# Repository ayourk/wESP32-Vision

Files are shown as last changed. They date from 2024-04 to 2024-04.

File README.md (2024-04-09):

# wESP32-Vision
OV2640 Camera module AddOn board for wESP32

## Description
This is my reinterpretation of [@xorbit](https://github.com/xorbit)'s Camera module prototype.  Sample Arduino project included.

### PCB Layout
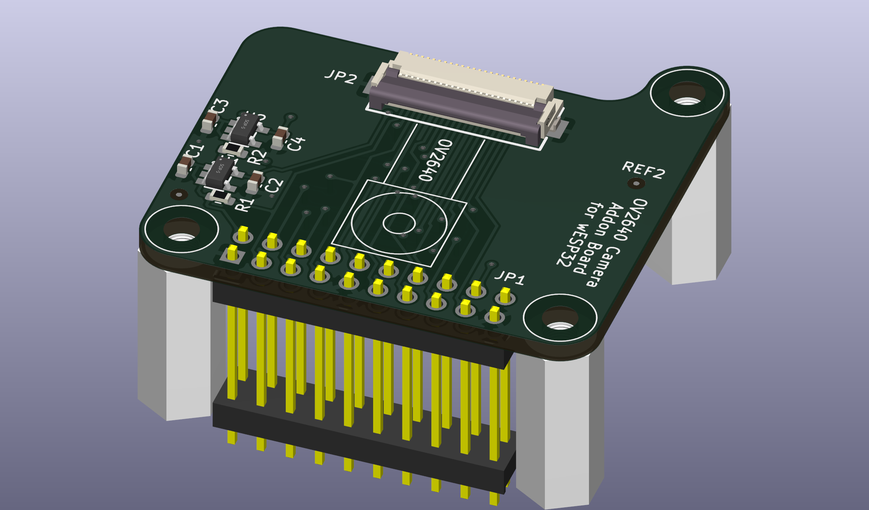
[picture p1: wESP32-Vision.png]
wESP32-Vision Board Image Apple II Prototyping Expansion Card (mini version)


### See Also
[xorbit's Projects](https://github.com/xorbit?tab=repositories)

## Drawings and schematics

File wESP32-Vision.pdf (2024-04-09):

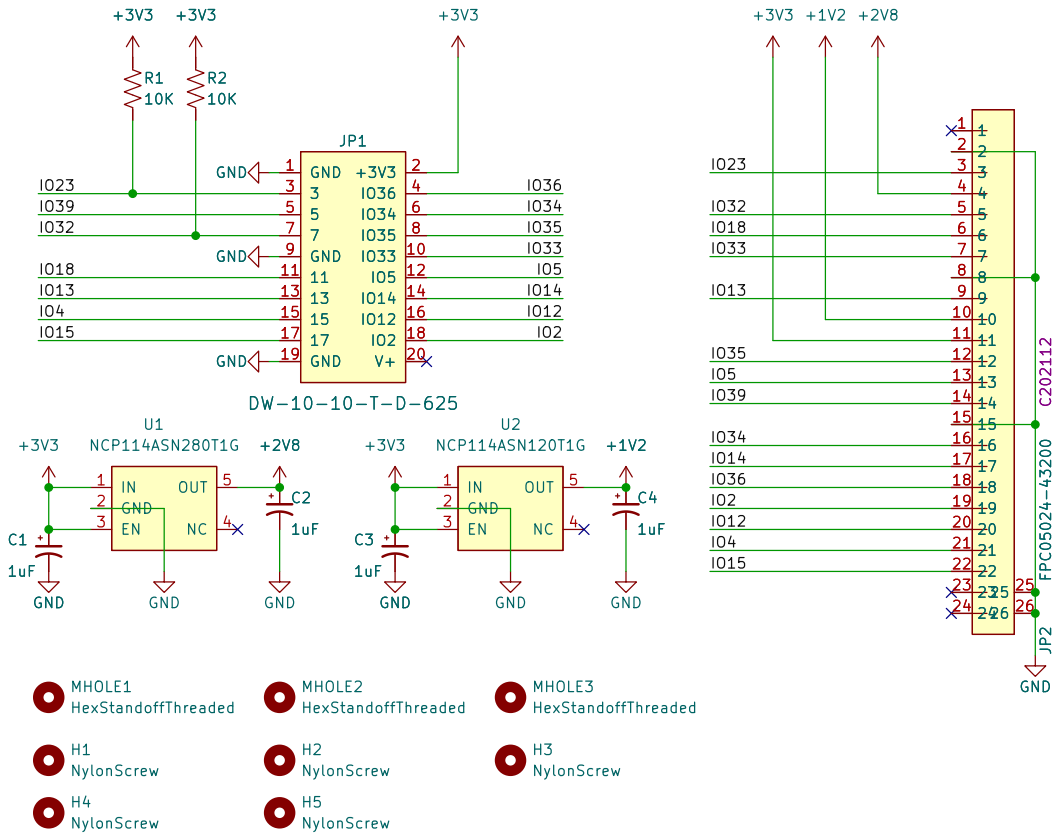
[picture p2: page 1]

Id: 1/1 Title: wESP32 Vision OV2640 Camera Addon Board

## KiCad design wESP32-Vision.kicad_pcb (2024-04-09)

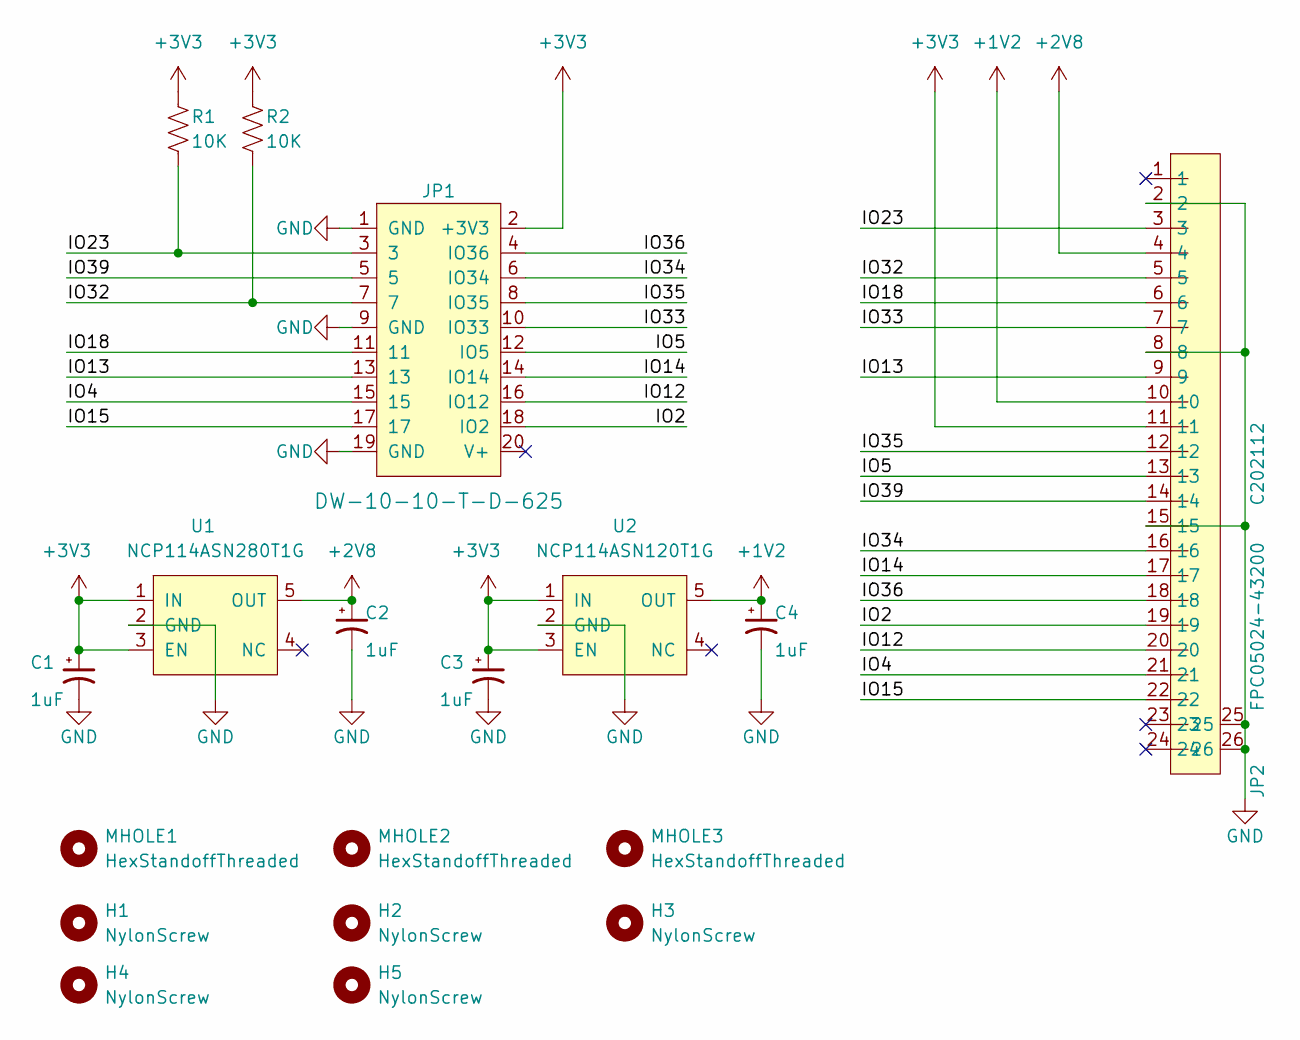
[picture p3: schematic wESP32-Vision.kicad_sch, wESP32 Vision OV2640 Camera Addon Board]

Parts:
C1, C2, C3, C4: 1uF; C_0603_1608Metric; MPN CL10A105KB8NNNC; Digi-Key_PN 1276-1860-1-ND
H1, H2, H3, H4, H5: NylonScrew; Screw; MPN 010440WF025; Digi-Key_PN RPC7726-ND
JP1: DW-10-10-T-D-625; SAMTEC_DW-10-XX-X-D-XXX; MPN DW-10-10-T-D-625; LCSC C62032
JP2: FPC05024-43200; FPC-SMD_FH12-24S-0.5SH-55; MPN FH12-24S-0.5SH(55); Digi-Key_PN HFJ124CT-ND
MHOLE1, MHOLE2, MHOLE3: HexStandoffThreaded; MountingHole_3mm; MPN 1902F; Digi-Key_PN 36-1902F-ND
R1, R2: 10K; R_0603_1608Metric; MPN ERJ-UP3F1002V; Digi-Key_PN 10-ERJ-UP3F1002VCT-ND
U1: NCP114ASN280T1G; TSOP-5_L3.0-W1.5-P0.95-LS2.8-BL; MPN NCP114ASN280T1G; LCSC C504890
U2: NCP114ASN120T1G; TSOP-5_L3.0-W1.5-P0.95-LS2.8-BL; MPN NCP114ASN120T1G; LCSC C512862

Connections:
+1V2: C4.1, JP2.10, U2.5 (OUT)
+2V8: C2.1, JP2.4, U1.5 (OUT)
+3V3: C1.1, C3.1, JP1.2 (+3V3), JP2.11, R1.1, R2.1, U1.1 (IN), U1.3 (EN), U2.1 (IN), U2.3 (EN)
/IO2: JP1.18 (IO2), JP2.19
/IO4: JP1.15, JP2.21
/IO5: JP1.12 (IO5), JP2.13
/IO12: JP1.16 (IO12), JP2.20
/IO13: JP1.13, JP2.9
/IO14: JP1.14 (IO14), JP2.17
/IO15: JP1.17, JP2.22
/IO18: JP1.11, JP2.6
/IO23: JP1.3, JP2.3, R1.2
/IO32: JP1.7, JP2.5, R2.2
/IO33: JP1.10 (IO33), JP2.7
/IO34: JP1.6 (IO34), JP2.16
/IO35: JP1.8 (IO35), JP2.12
/IO36: JP1.4 (IO36), JP2.18
/IO39: JP1.5, JP2.14
GND: C1.2, C2.2, C3.2, C4.2, JP1.1 (GND), JP1.9 (GND), JP1.19 (GND), JP2.2, JP2.8, JP2.15, JP2.25, JP2.26, U1.2 (GND), U2.2 (GND)

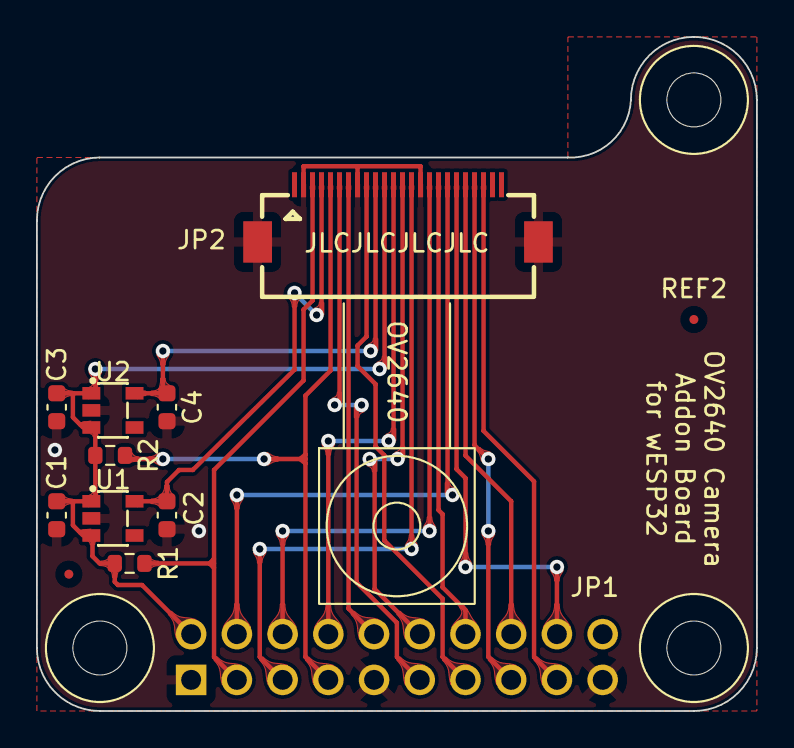
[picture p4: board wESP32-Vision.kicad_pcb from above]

Board: 2 copper layers, 40.0 x 37.5 mm, 21 parts (1 on the bottom side), 19 nets.

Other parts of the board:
GRAPHIC: OV2640
REF1, REF2: Fiducial_0.5mm_Mask1.5mm

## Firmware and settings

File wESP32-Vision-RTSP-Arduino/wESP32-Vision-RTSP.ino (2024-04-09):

#include "OV2640.h"
#include <ETH.h>
#include <WiFi.h>
#include <WebServer.h>
#include <WiFiClient.h>

#include "OV2640Streamer.h"
#include "CRtspSession.h"

#define ENABLE_WEBSERVER
#define ENABLE_RTSPSERVER

OV2640 cam;

#ifdef ENABLE_WEBSERVER
WebServer server(80);
#endif

#ifdef ENABLE_RTSPSERVER
WiFiServer rtspServer(8554);
#endif


#ifdef ENABLE_WEBSERVER
void handle_jpg_stream(void)
{
    WiFiClient client = server.client();
    String response = "HTTP/1.1 200 OK\r\n";
    response += "Content-Type: multipart/x-mixed-replace; boundary=frame\r\n\r\n";
    server.sendContent(response);

    while (1)
    {
        cam.run();
        if (!client.connected())
            break;
        response = "--frame\r\n";
        response += "Content-Type: image/jpeg\r\n\r\n";
        server.sendContent(response);

        client.write((char *)cam.getfb(), cam.getSize());
        server.sendContent("\r\n");
        if (!client.connected())
            break;
    }
}

void handle_jpg(void)
{
    WiFiClient client = server.client();

    cam.run();
    if (!client.connected())
    {
        return;
    }
    String response = "HTTP/1.1 200 OK\r\n";
    response += "Content-disposition: inline; filename=capture.jpg\r\n";
    response += "Content-type: image/jpeg\r\n\r\n";
    server.sendContent(response);
    client.write((char *)cam.getfb(), cam.getSize());
}

void handleNotFound()
{
    String message = "Server is running!\n\n";
    message += "URI: ";
    message += server.uri();
    message += "\nMethod: ";
    message += (server.method() == HTTP_GET) ? "GET" : "POST";
    message += "\nArguments: ";
    message += server.args();
    message += "\n";
    server.send(200, "text/plain", message);
}
#endif

// Ethernet event handler

void handleEvent(WiFiEvent_t event)
{
  switch (event) {
    case SYSTEM_EVENT_ETH_START:
      Serial.println("ETH Started");
      //set eth hostname here
      ETH.setHostname("wesp32-vision");
      break;
    case SYSTEM_EVENT_ETH_CONNECTED:
      Serial.println("ETH Connected");
      break;
    case SYSTEM_EVENT_ETH_GOT_IP:
      Serial.print("ETH MAC: ");
      Serial.print(ETH.macAddress());
      Serial.print(", IPv4: ");
      Serial.print(ETH.localIP());
      if (ETH.fullDuplex()) {
        Serial.print(", FULL_DUPLEX");
      }
      Serial.print(", ");
      Serial.print(ETH.linkSpeed());
      Serial.println("Mbps");
      break;
    case SYSTEM_EVENT_ETH_DISCONNECTED:
      Serial.println("ETH Disconnected");
      break;
    case SYSTEM_EVENT_ETH_STOP:
      Serial.println("ETH Stopped");
      break;
    default:
      break;
  }
}

void setup()
{
    // Start serial console
    Serial.begin(115200);

    // Attach the callback event handler
    WiFi.onEvent(handleEvent);
    // Start Ethernet
    ETH.begin();

    // Start the camera
    cam.init(wesp32_vision_config);

#ifdef ENABLE_WEBSERVER
    server.on("/", HTTP_GET, handle_jpg_stream);
    server.on("/jpg", HTTP_GET, handle_jpg);
    server.onNotFound(handleNotFound);
    server.begin();
#endif

#ifdef ENABLE_RTSPSERVER
    rtspServer.begin();
#endif
}

CStreamer *streamer;
CRtspSession *session;
WiFiClient client; // FIXME, support multiple clients

void loop()
{
#ifdef ENABLE_WEBSERVER
    server.handleClient();
#endif

#ifdef ENABLE_RTSPSERVER
    uint32_t msecPerFrame = 100;
    static uint32_t lastimage = millis();

    // If we have an active client connection, just service that until gone
    // (FIXME - support multiple simultaneous clients)
    if(session) {
        session->handleRequests(0); // we don't use a timeout here,
        // instead we send only if we have new enough frames

        uint32_t now = millis();
        if(now > lastimage + msecPerFrame || now < lastimage) { // handle clock rollover
            session->broadcastCurrentFrame(now);
            lastimage = now;

            // check if we are overrunning our max frame rate
            now = millis();
            if(now > lastimage + msecPerFrame)
                printf("warning exceeding max frame rate of %d ms\n", now - lastimage);
        }

        if(session->m_stopped) {
            delete session;
            delete streamer;
            session = NULL;
            streamer = NULL;
        }
    }
    else {
        client = rtspServer.accept();

        if(client) {
            streamer = new OV2640Streamer(&client, cam);             // our streamer for UDP/TCP based RTP transport
            session = new CRtspSession(&client, streamer); // our threads RTSP session and state
        }
    }
#endif
}

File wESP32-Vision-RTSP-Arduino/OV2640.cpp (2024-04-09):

#include "OV2640.h"

#define TAG "OV2640"

// definitions appropriate for the ESP32-CAM devboard (and most clones)
camera_config_t esp32cam_config {

    .pin_pwdn = -1,
    .pin_reset = 15,

    .pin_xclk = 27,

    .pin_sscb_sda = 25,
    .pin_sscb_scl = 23,

    .pin_d7 = 19,
    .pin_d6 = 36,
    .pin_d5 = 18,
    .pin_d4 = 39,
    .pin_d3 = 5,
    .pin_d2 = 34,
    .pin_d1 = 35,
    .pin_d0 = 17,
    .pin_vsync = 22,
    .pin_href = 26,
    .pin_pclk = 21,
    .xclk_freq_hz = 20000000,
    .ledc_timer = LEDC_TIMER_0,
    .ledc_channel = LEDC_CHANNEL_0,
    .pixel_format = PIXFORMAT_JPEG,
    // .frame_size = FRAMESIZE_UXGA, // needs 234K of framebuffer space
    // .frame_size = FRAMESIZE_SXGA, // needs 160K for framebuffer
    // .frame_size = FRAMESIZE_XGA, // needs 96K or even smaller FRAMESIZE_SVGA - can work if using only 1 fb
    .frame_size = FRAMESIZE_SVGA,
    .jpeg_quality = 12,               //0-63 lower numbers are higher quality
    .fb_count = 2 // if more than one i2s runs in continous mode.  Use only with jpeg
};

camera_config_t esp32cam_aithinker_config {

    .pin_pwdn = 32,
    .pin_reset = -1,

    .pin_xclk = 0,

    .pin_sscb_sda = 26,
    .pin_sscb_scl = 27,

    // Note: LED GPIO is apparently 4 not sure where that goes
    // per https://github.com/donny681/ESP32_CAMERA_QR/blob/e4ef44549876457cd841f33a0892c82a71f35358/main/led.c
    .pin_d7 = 35,
    .pin_d6 = 34,
    .pin_d5 = 39,
    .pin_d4 = 36,
    .pin_d3 = 21,
    .pin_d2 = 19,
    .pin_d1 = 18,
    .pin_d0 = 5,
    .pin_vsync = 25,
    .pin_href = 23,
    .pin_pclk = 22,
    .xclk_freq_hz = 20000000,
    .ledc_timer = LEDC_TIMER_1,
    .ledc_channel = LEDC_CHANNEL_1,
    .pixel_format = PIXFORMAT_JPEG,
    // .frame_size = FRAMESIZE_UXGA, // needs 234K of framebuffer space
    // .frame_size = FRAMESIZE_SXGA, // needs 160K for framebuffer
    // .frame_size = FRAMESIZE_XGA, // needs 96K or even smaller FRAMESIZE_SVGA - can work if using only 1 fb
    .frame_size = FRAMESIZE_SVGA,
    .jpeg_quality = 12,               //0-63 lower numbers are higher quality
    .fb_count = 2 // if more than one i2s runs in continous mode.  Use only with jpeg
};

camera_config_t esp32cam_ttgo_t_config {

    .pin_pwdn = 26,
    .pin_reset = -1,

    .pin_xclk = 32,

    .pin_sscb_sda = 13,
    .pin_sscb_scl = 12,

    .pin_d7 = 39,
    .pin_d6 = 36,
    .pin_d5 = 23,
    .pin_d4 = 18,
    .pin_d3 = 15,
    .pin_d2 = 4,
    .pin_d1 = 14,
    .pin_d0 = 5,
    .pin_vsync = 27,
    .pin_href = 25,
    .pin_pclk = 19,
    .xclk_freq_hz = 20000000,
    .ledc_timer = LEDC_TIMER_0,
    .ledc_channel = LEDC_CHANNEL_0,
    .pixel_format = PIXFORMAT_JPEG,
    .frame_size = FRAMESIZE_SVGA,
    .jpeg_quality = 12, //0-63 lower numbers are higher quality
    .fb_count = 2 // if more than one i2s runs in continous mode.  Use only with jpeg
};

// Definition for the wESP32-Vision
camera_config_t wesp32_vision_config {

    .pin_pwdn = -1,
    .pin_reset = 18,

    .pin_xclk = 5,

    .pin_sscb_sda = 23,
    .pin_sscb_scl = 32,

    .pin_d7 = 35,
    .pin_d6 = 39,
    .pin_d5 = 34,
    .pin_d4 = 36,
    .pin_d3 = 12,
    .pin_d2 = 15,
    .pin_d1 = 4,
    .pin_d0 = 2,
    .pin_vsync = 33,
    .pin_href = 13,
    .pin_pclk = 14,
    .xclk_freq_hz = 10000000,
    .ledc_timer = LEDC_TIMER_0,
    .ledc_channel = LEDC_CHANNEL_0,
    .pixel_format = PIXFORMAT_JPEG,
    // .frame_size = FRAMESIZE_UXGA, // needs 234K of framebuffer space
    // .frame_size = FRAMESIZE_SXGA, // needs 160K for framebuffer
    // .frame_size = FRAMESIZE_XGA, // needs 96K or even smaller FRAMESIZE_SVGA - can work if using only 1 fb
    .frame_size = FRAMESIZE_VGA,
    .jpeg_quality = 12,               //0-63 lower numbers are higher quality
    .fb_count = 2 // if more than one i2s runs in continous mode.  Use only with jpeg
};



void OV2640::run(void)
{
    if(fb)
        //return the frame buffer back to the driver for reuse
        esp_camera_fb_return(fb);

    fb = esp_camera_fb_get();
}

void OV2640::runIfNeeded(void)
{
    if(!fb)
        run();
}

int OV2640::getWidth(void)
{
    runIfNeeded();
    return fb->width;
}

int OV2640::getHeight(void)
{
    runIfNeeded();
    return fb->height;
}

size_t OV2640::getSize(void)
{
    runIfNeeded();
    return fb->len;
}

uint8_t *OV2640::getfb(void)
{
    runIfNeeded();
    return fb->buf;
}

framesize_t OV2640::getFrameSize(void)
{
    return _cam_config.frame_size;
}

void OV2640::setFrameSize(framesize_t size)
{
    _cam_config.frame_size = size;
}

pixformat_t OV2640::getPixelFormat(void)
{
    return _cam_config.pixel_format;
}

void OV2640::setPixelFormat(pixformat_t format)
{
    switch (format)
    {
    case PIXFORMAT_RGB565:
    case PIXFORMAT_YUV422:
    case PIXFORMAT_GRAYSCALE:
    case PIXFORMAT_JPEG:
        _cam_config.pixel_format = format;
        break;
    default:
        _cam_config.pixel_format = PIXFORMAT_GRAYSCALE;
        break;
    }
}


esp_err_t OV2640::init(camera_config_t config)
{
    memset(&_cam_config, 0, sizeof(_cam_config));
    memcpy(&_cam_config, &config, sizeof(config));

    esp_err_t err = esp_camera_init(&_cam_config);
    if (err != ESP_OK)
    {
        printf("Camera probe failed with error 0x%x", err);
        return err;
    }
    // ESP_ERROR_CHECK(gpio_install_isr_service(0));

    return ESP_OK;
}
